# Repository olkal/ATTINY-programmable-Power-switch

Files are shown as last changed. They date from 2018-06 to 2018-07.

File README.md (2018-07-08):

# ATTINY Power switch
This programmable MOSFET high side on/off power switch is based on the ATTINY85 chip and is intended for battery powered devices.

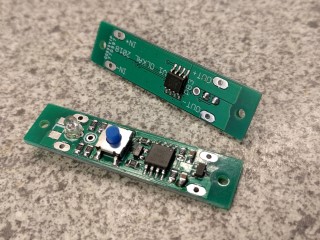
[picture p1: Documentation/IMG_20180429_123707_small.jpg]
ATTINY-Power-switch


- 2-3 Lipo cells 
- Max operating voltage 16.0V (18V never exceed)
- Max current: needs to be tested, but up to 5A should be safe. See MOSFET data sheet for info.
- Power consumption in "off" mode with BOD disabled: 3uA
- Power consumption in "off" mode with BOD enabled: 20uA

### Configurable features in config.h file:
- LED behaviour
- Low battery voltage threshold, LED warning
- Very low battery voltage threshold, power off
- Button press and hold for a set time for power on
- Button press and hold for set time for power off
- Timer, delayed power off
- Timer, after power has been on for set time, switch power off
- PB3 pin signal (to for example a Raspberry Pi) initiating controlled shut-down, then switch the power off after a set time delay
-  +lots of other possibilities...

### Battery/voltage features using button switch:
- Auto calibrating internal voltmeter
- Auto set number of cells

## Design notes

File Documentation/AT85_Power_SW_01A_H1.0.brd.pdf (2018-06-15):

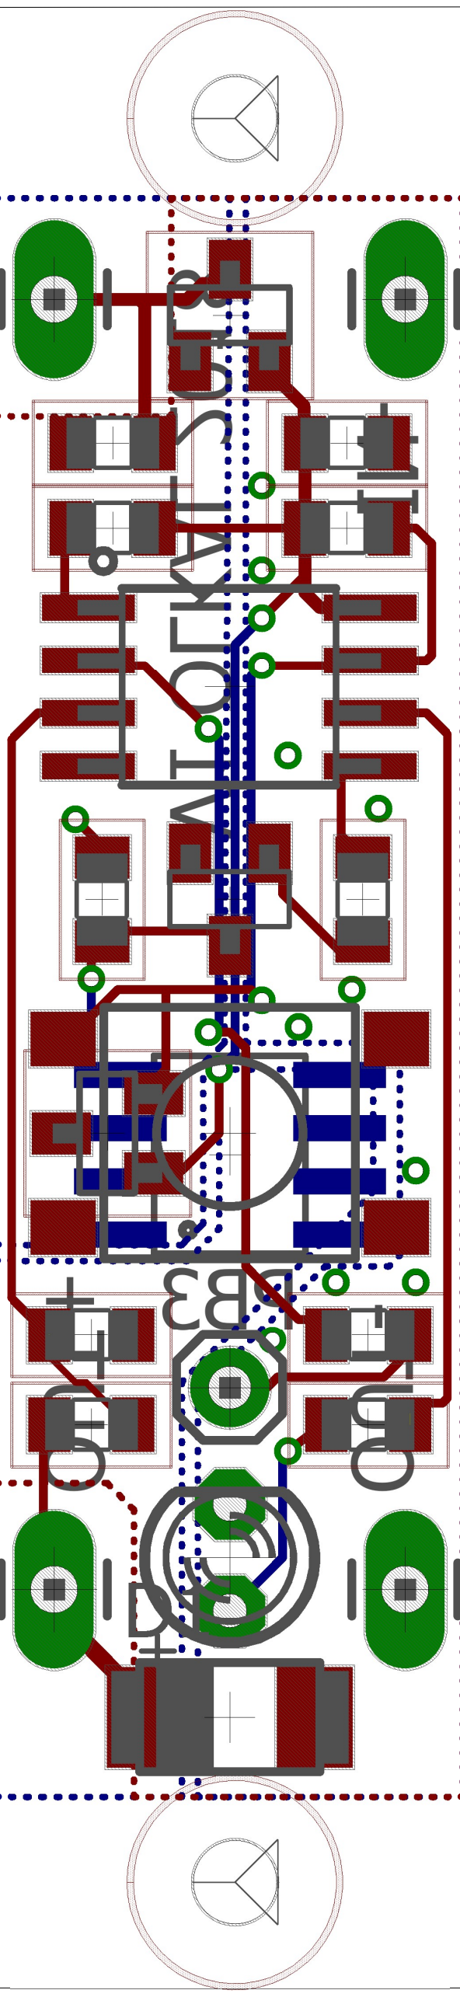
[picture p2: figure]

14.06.2018 20.10 f=4.00 D:\Dropbox\Hobby\Eagle\projects\Various\AT85_Power_SW\AT85_Power_SW_01A_H1.0.brd

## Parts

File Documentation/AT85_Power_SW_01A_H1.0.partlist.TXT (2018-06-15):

Partlist

Exported from AT85_Power_SW_01A_H1.0.sch at 14.06.2018 19.48

EAGLE Version 8.2.1 Copyright (c) 1988-2017 Autodesk, Inc.

Assembly variant: 

Part     Value             Device                               Package                       Library             Sheet

C2       4.7uF/25V         CAP_SMD_C0805                        C0805                         OKA-Cap-Resistor    1 
C3       4.7uF/25V         CAP_SMD_C0805                        C0805                         OKA-Cap-Resistor    1
D1                         DIODE-DO-214AC                       DO-214AC                      diode               1 -> Otional diode for inductive loads
IC1      3.3V              MCP1703A 3.3V regulator              SOT23                         linear              1
IC2      SL353             SL353                                SOT23                         OKA-IC              1 -> Otional hall sensor
LED1                       LED3MM                               LED3MM                        adafruit            1
Q1       P-MOSFET SI4459AD MOSFET-PCHANNEL                      SO08                          User-Submitted      1
R1       10k               RESISTOR_SMDR0805                    R0805                         OKA-Cap-Resistor    1
R2       100k              RESISTOR_SMDR0805                    R0805                         OKA-Cap-Resistor    1
R3       22k               RESISTOR_SMDR0805                    R0805                         OKA-Cap-Resistor    1
R4       1k5               RESISTOR_SMDR0805                    R0805                         OKA-Cap-Resistor    1
R5       220R              RESISTOR_SMDR0805                    R0805                         OKA-Cap-Resistor    1
R6       220R              RESISTOR_SMDR0805                    R0805                         OKA-Cap-Resistor    1
R7       10k               RESISTOR_SMDR0805                    R0805                         OKA-Cap-Resistor    1
R8       10k               RESISTOR_SMDR0805                    R0805                         OKA-Cap-Resistor    1
S1                         MOMENTARY-SWITCH-SPST-SMD-6.2MM-TALL TACTILE_SWITCH_SMD_6.2MM_TALL SparkFun-Switches   1
T1       2N2222            MMBT2222ALT1-NPN-SOT23-BEC           SOT23-BEC                     transistor          1
U1       Tiny85-20-SMT     ATTINY45TINY85-20-SMT                SO08-EIAJ_MCU                 SparkFun-Retired    1

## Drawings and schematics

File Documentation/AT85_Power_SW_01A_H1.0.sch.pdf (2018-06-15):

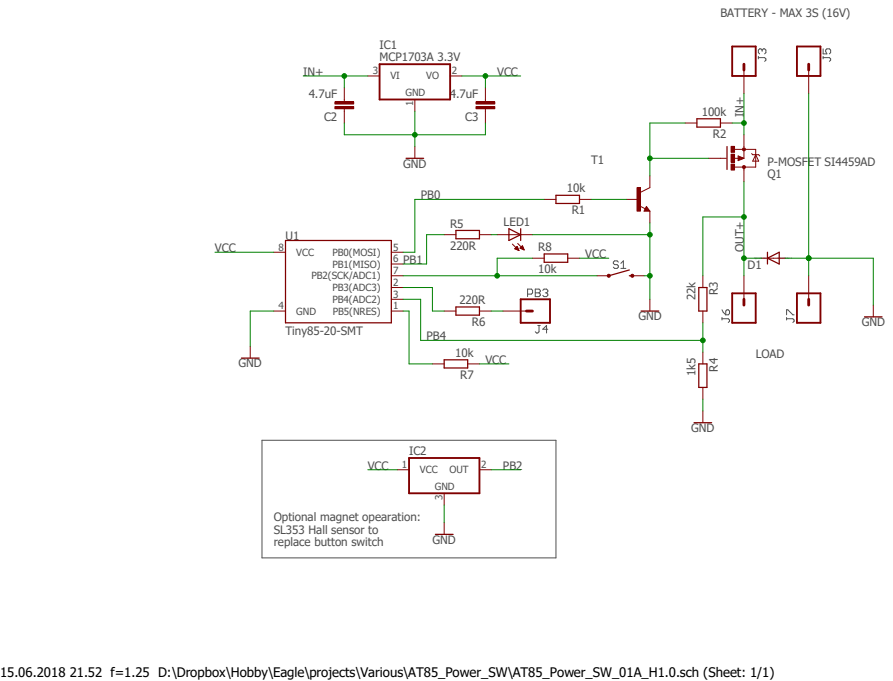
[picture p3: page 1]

15.06.2018 21.52 f=1.25 D:\Dropbox\Hobby\Eagle\projects\Various\AT85_Power_SW\AT85_Power_SW_01A_H1.0.sch (Sheet: 1/1)

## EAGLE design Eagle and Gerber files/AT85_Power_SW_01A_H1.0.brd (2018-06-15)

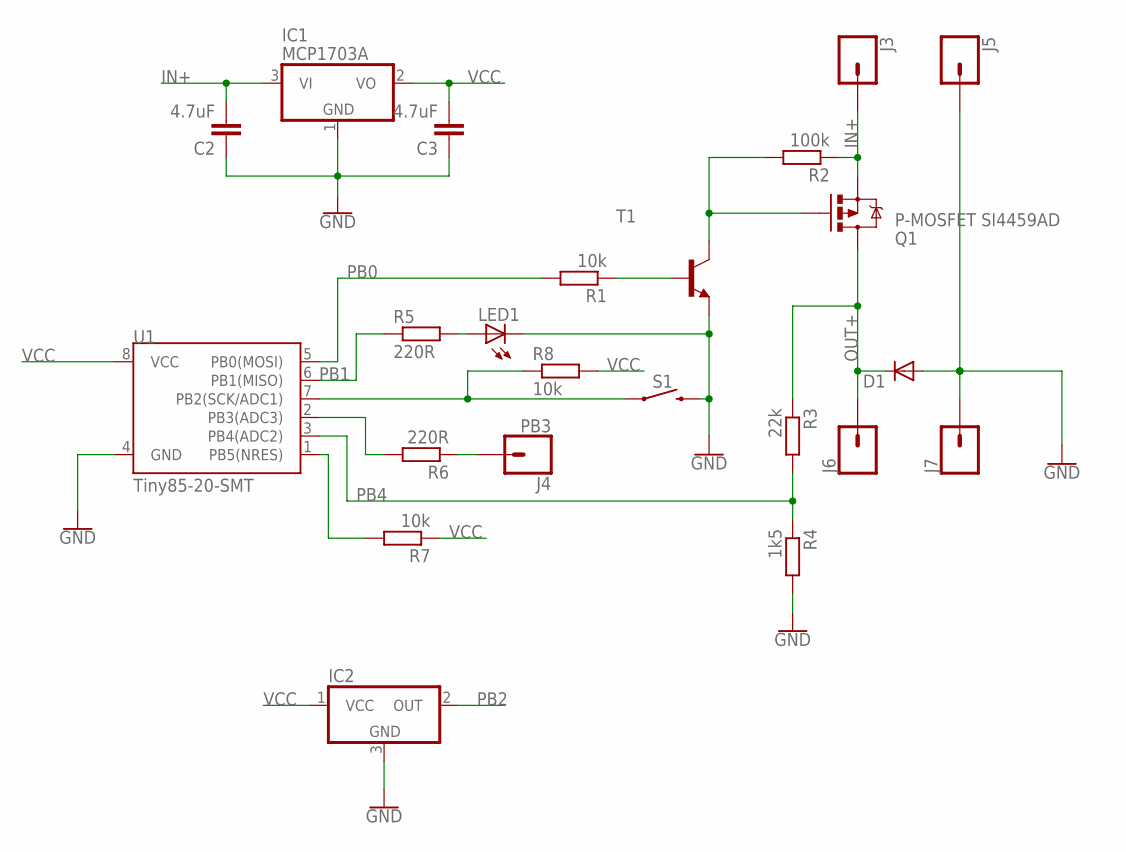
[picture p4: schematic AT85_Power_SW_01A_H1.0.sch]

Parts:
C2, C3: 4.7uF; C0805
D1: DIODE-DO-214AC; DO-214AC
IC1: MCP1703A; SOT23
IC2: SL353; SOT23
J3, J5, J6, J7: CONN_01PTH_LONGPAD; 1X01_LONGPAD
J4: PB3; 1X01
LED1: LED3MM
Q1: P-MOSFET SI4459AD; SO08
R1, R7, R8: 10k; R0805
R2: 100k; R0805
R3: 22k; R0805
R4: 1k5; R0805
R5, R6: 220R; R0805
S1: TACTILE_SWITCH_SMD_6.2MM_TALL
T1: MMBT2222ALT1-NPN-SOT23-BEC; SOT23-BEC
U1: Tiny85-20-SMT; SO08-EIAJ_MCU

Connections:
GATE: Q1.4 (G), R2.2, T1.C
GND: C2.1, C3.1, D1.A, IC1.1 (GND), IC2.3 (GND), J5.1, J7.1, LED1.K (C), R4.2, S1.B2 (2), T1.E, U1.4 (GND)
IN+: C2.2, IC1.3 (VI), J3.1, Q1.1 (S), Q1.2 (S), Q1.3 (S), R2.1
unnamed: LED1.A, R5.2
unnamed: R1.1, T1.B
OUT+: D1.C, J6.1, Q1.5 (D), Q1.6 (D), Q1.7 (D), Q1.8 (D), R3.1
PB0: R1.2, U1.5 (PB0(MOSI))
PB1: R5.1, U1.6 (PB1(MISO))
PB2: IC2.2 (OUT), R8.1, S1.A2 (1), U1.7 (PB2(SCK/ADC1))
PB3: R6.2, U1.2 (PB3(ADC3))
PB3_: J4.1, R6.1
PB4: R3.2, R4.1, U1.3 (PB4(ADC2))
RST: R7.2, U1.1 (PB5(NRES))
VCC: C3.2, IC1.2 (VO), IC2.1 (VCC), R7.1, R8.2, U1.8 (VCC)

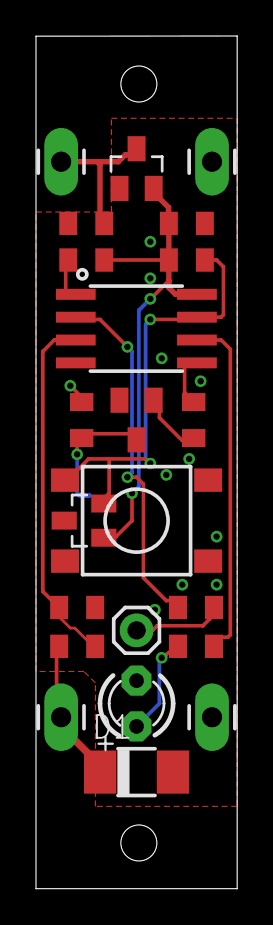
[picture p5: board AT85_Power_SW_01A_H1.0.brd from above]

Board: 2 copper layers, 11.2 x 47.4 mm, 23 parts (1 on the bottom side), 14 nets.

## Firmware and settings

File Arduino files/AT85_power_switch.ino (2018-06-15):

#include <Arduino.h>
#include <avr/interrupt.h>
#include <avr/sleep.h>
#include <EEPROM.h>
#include "config.h"

#define DEBOUNCE_MS                 30
#define POWER_OFF                   0x00
#define POWER_ON                    0x01
#define POWER_OFF_DELAY_WAIT        0x02
#define POWER_OFF_REQUEST           0x03
#define BATTERY_EMPTY               0x00
#define BATTERY_VERY_LOW            0x01
#define BATTERY_LOW                 0x02
#define BATTERY_GOOD                0x03
#define CELL_COUNT_MIN              0x01
#define CELL_COUNT_MAX              0x03

byte mosfetPin = 0;
byte ledPin = 1;
byte buttonPin = 2;
byte auxPin = 3;
byte battSensePin = A2;

int lastBattVal;
boolean lastButtonState = 1;
boolean buttonHold;
unsigned long buttonHoldTime;
unsigned long lastButtonAction;
unsigned long lastReadBattVoltage;
byte ledValue;
long ledTime;
long powerOnTime;
byte powerState = 0; //0=off, 1=on, 2=delayed shut down
byte battStatus = BATTERY_GOOD;
unsigned int voltageCalFactor;
byte cellCount;

void setup() {
  pinMode(ledPin, OUTPUT);
  pinMode(mosfetPin, OUTPUT);
  analogReference(INTERNAL);
  voltageCalFactor = word(EEPROM.read(0), EEPROM.read(1));
  cellCount = EEPROM.read(2);
  setPower(POWER_ON);
  delay(10);
  setConfig();
  for (byte c = 0; c < cellCount; c++) {
    digitalWrite(ledPin, 1);
    delay(200);
    digitalWrite(ledPin, 0);
    delay(200);
  }
  delay(200);
}

void loop() {
  checkSleep();
  checkTimerPwrOff();
  ledControl();
  if (powerState == POWER_OFF_DELAY_WAIT) {
    if ((lastButtonAction + AUX_SHTD_DELAY) < millis()) {
      setPower(POWER_OFF);
    }
  }
  else {
    button();
  }

  if ((lastReadBattVoltage + 250) < millis()) {
    readBattVoltage();
    lastReadBattVoltage = millis();
  }
  handleBattVoltage();
}

//**********************************

void ISR_wake()
{
}

void checkSleep() {
  if ((powerState == POWER_OFF) && (digitalRead(buttonPin) == HIGH)) {
    if ((lastButtonAction + 2000) < millis()) {
      if (SLEEP_ENABLE) {
        CPU_sleep();
      }
    }
  }
}

void checkTimerPwrOff() {
  if (TIMER_PWR_OFF_DELAY) {
    if (millis() > (powerOnTime + TIMER_PWR_OFF_DELAY)) {
      setPower(POWER_OFF_REQUEST);
    }
  }
}

void CPU_sleep()
{
  pinMode(auxPin, OUTPUT);
  pinMode(battSensePin, OUTPUT);
  digitalWrite(battSensePin, LOW);
  digitalWrite(auxPin, LOW);
  digitalWrite(ledPin, LOW);
  ADCSRA &= ~(1 << ADEN); //Disable ADC
  //byte gtccr = GTCCR;
  //GTCCR = 0;
  set_sleep_mode(SLEEP_MODE_PWR_DOWN);
  sleep_enable();
  attachInterrupt(0, ISR_wake, LOW);
  sleep_cpu(); //go to sleep
  detachInterrupt(0); //wake up
  sleep_disable(); 
  pinMode(battSensePin, INPUT);
  ADCSRA |= (1 << ADEN); //Enable ADC
  //GTCCR = gtccr;
  lastReadBattVoltage -= 250;
  lastButtonState = HIGH;
  pinMode(auxPin, INPUT);
}

void button() {
  boolean _buttonState = digitalRead(buttonPin);
  if (_buttonState != lastButtonState) {
    if (_buttonState == LOW) {
      if ((lastButtonAction + DEBOUNCE_MS) < millis()) {
        buttonHold = true;
      }
    }
    else {
      buttonHold = false;
    }
    lastButtonAction = millis();
    lastButtonState = _buttonState;
  }

  if (buttonHold) {
    if (powerState == POWER_OFF) {
      if ((lastButtonAction + BUTTON_PWR_ON_HOLD_TIME) <= millis()) {
        setPower(POWER_ON);
        buttonHold = false;
      }
    }
    else if (powerState == POWER_ON) {
      if ((lastButtonAction + BUTTON_PWR_OFF_HOLD_TIME) <= millis()) {
        setPower(POWER_OFF_REQUEST);
        buttonHold = false;
      }
    }
  }
}

void setPower(byte newlevel) {
  if (newlevel == POWER_OFF) {
    digitalWrite(mosfetPin, LOW);
    powerState = POWER_OFF;
  }
  else if (newlevel == POWER_ON) {
    digitalWrite(mosfetPin, HIGH);
    powerState = POWER_ON;
    powerOnTime = millis();
  }

  else if (newlevel == POWER_OFF_REQUEST) {
    if (powerState == POWER_ON) {
      if (AUX_IS_SHTD_SIGNAL_OUT) {
        powerState = POWER_OFF_DELAY_WAIT; //wait until power-off delay has counted down (RPI shut-down) 
        lastButtonAction = millis();
        auxControl();
      }
      else {
        digitalWrite(mosfetPin, LOW);
        powerState = POWER_OFF;
      }
    }
  }
}

void auxControl() {
  pinMode(auxPin, OUTPUT);
  boolean _val = AUX_SHTD_SIGNAL_HIGH_LOW;
  digitalWrite(auxPin, _val);
  delay(AUX_SHTD_SIGNAL_LENGTH);
  _val = ~_val; //flip
  digitalWrite(auxPin, _val);
  pinMode(auxPin, INPUT);
}

void ledControl() {
  int _ledontime;
  int _ledofftime;
  boolean _ledBlink;
  if (powerState == POWER_OFF) {
    ledValue = LED_OFF_BRIGHTNESS;
  }
  else if (powerState == POWER_ON) {
    if (battStatus == BATTERY_GOOD) {
      _ledBlink = 0;
      ledValue = LED_ON_BRIGHTNESS;
    }
    else if (battStatus == BATTERY_LOW) {
      _ledBlink = 1;
      _ledontime = LED_BLINK_ON_TIME * 2;
      _ledofftime = LED_BLINK_OFF_TIME;
    }
    else if (battStatus == BATTERY_EMPTY) {
      _ledBlink = 1;
      _ledontime = LED_BLINK_ON_TIME;
      _ledofftime = LED_BLINK_OFF_TIME;
    }
  }
  else if (powerState == POWER_OFF_DELAY_WAIT) {
    _ledBlink = 1;
    _ledontime = LED_BLINK_FAST_ON_TIME;
    _ledofftime = LED_BLINK_FAST_OFF_TIME;
  }
  if (_ledBlink) {
    if (ledTime < millis()) {
      if (ledValue < LED_ON_BRIGHTNESS) {
        ledValue = LED_ON_BRIGHTNESS;
        ledTime = millis() + _ledontime;
      }
      else {
        ledValue = LED_OFF_BRIGHTNESS;
        ledTime = millis() + _ledofftime;
      }
    }
  }
  analogWrite(ledPin, ledValue);
}

int readBattVoltage() {
  if (powerState) { //mosfet must be switched on for analog read battery voltage
    int _val;
    int _newval;
    _newval = analogRead(battSensePin);
    if (lastBattVal < _newval) { //use the highest of the two last conversions
      _val = _newval;
    }
    else {
      _val = lastBattVal;
    }

    _val = ((long)_val * (long)voltageCalFactor) / 100L;
    if (_val > (cellCount * CELL_VOLTAGE_LOW)) {
      battStatus = BATTERY_GOOD;
    }
    else if (_val > (cellCount * CELL_VOLTAGE_VERY_LOW)) {
      battStatus = BATTERY_LOW;
    }
    else if (_val > (cellCount * CELL_VOLTAGE_EMPTY)) {
      battStatus = BATTERY_VERY_LOW;
    }
    else {
      battStatus = BATTERY_EMPTY;
    }
    lastBattVal = _newval;
    return _val;
  }
}

void handleBattVoltage() {
  if ((battStatus == BATTERY_LOW) && BATTERY_LOW_AUTO_OFF) {
    if (millis() < (powerOnTime + 3000)) {
      setPower(POWER_OFF);
    }
    else {
      setPower(POWER_OFF_REQUEST);
    }
  }
  if ((battStatus == BATTERY_VERY_LOW) && BATTERY_VERY_LOW_AUTO_OFF) {
    if (millis() < (powerOnTime + 3000)) {
      setPower(POWER_OFF);
    }
    else {
      setPower(POWER_OFF_REQUEST);
    }
  }
  else if ((battStatus == BATTERY_EMPTY) && BATTERY_EMPTY_AUTO_OFF) {
    setPower(POWER_OFF);
  }
}

void setConfig() {
  if (digitalRead(buttonPin) == LOW) {
    boolean _buttonhold = 1;
    boolean _done = 0;
    digitalWrite(ledPin, 0);
    long _button_release_time = 0;
    while (1) {
      if ((millis() > 5000) && (millis() < 5050)) digitalWrite(ledPin, 1);
      else if ((millis() > 10000) && (millis() < 10050)) digitalWrite(ledPin, 1);
      else digitalWrite(ledPin, 0);

      if ((digitalRead(buttonPin) == HIGH) && (_button_release_time == 0)) {
        _button_release_time = millis();
      }

      else if (_button_release_time > 10000) {
        digitalWrite(ledPin, 1);
        calibrateBattVoltage();
        while (1) {
          digitalWrite(ledPin, 0);
          delay(1000);
          digitalWrite(ledPin, 1);
          delay(1000);
        }
      }
      else if (_button_release_time > 5000) {
        digitalWrite(ledPin, 1);
        int v = readBattVoltage();
        int _cellcount = v / CELL_VOLTAGE_LOW;
        if ((_cellcount > CELL_COUNT_MIN) && (_cellcount <= CELL_COUNT_MAX)) {
          EEPROM.write(2, (_cellcount & 0xFF));
          cellCount = EEPROM.read(2);
          while (1) {
            for (byte c = 0; c < cellCount; c++) {
              digitalWrite(ledPin, 1);
              delay(200);
              digitalWrite(ledPin, 0);
              delay(200);
            }
            delay(1000);
          }
        }
      }
    }
  }
}

int calibrateBattVoltage() {
  setPower(POWER_ON);
  delay(100);
  int _val = 0;
  for (byte i = 0; i < 10; i++) { //repeated readings
    _val += analogRead(battSensePin);
    delay(100);
  }
  _val = ((long)AUTO_CAL_VOLTAGE * 1000) / _val;

  EEPROM.write(0, (_val >> 8 & 0xFF)); //save new value, high byte
  EEPROM.write(1, (_val & 0xFF)); //save new value, low byte
}

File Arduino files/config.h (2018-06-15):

/*
   ATTINY fuse settings:
   1MHz (internal)
   BOD 2.7V (BOD 1.8V can be used for ATTINY85V) 
*/
/*
  Instructions to auto calibrate internal voltmeter:
    1. Disconnect load side of the switch
    2. Press and hold button
    3. Connect 5.00V power supply on battery side
    4. Release button after the second LED blink (10 seconds)
    5. LED will start to blink slowly when calibration is done
    6. Disconnect and reconnect adjustable power supply
    7. Test the calibration by adjusting the supply voltage while observing LED

  Instructions to configure the battery cell count:
    1. Disconnect load side of the switch
    2. Press and hold button
    3. Connect the battery
    4. Release button after the first LED blink (5 seconds)
    5. LED will start to blink the number of cells detected
    6. Disconnect and reconnect battery    
*/

//configue mcu sleep and low battery warning/power off levels:
#define SLEEP_ENABLE                1       //Enable mcu deep sleep when power off (off-state, low power consumption) 
#define BATTERY_LOW_AUTO_OFF        0       //Enable auto power off if voltage is less than CELL_VOLTAGE_LOW 
#define BATTERY_VERY_LOW_AUTO_OFF   1       //Enable auto power off if voltage is less than CELL_VOLTAGE_VERY_LOW
#define BATTERY_EMPTY_AUTO_OFF      1       //Enable imidiate power off if voltage is less than CELL_VOLTAGE_EMPTY
#define AUTO_CAL_VOLTAGE            500     //supplied voltage to VIN when performing auto calibration, unit 1/100 volt
#define CELL_VOLTAGE_EMPTY          250     //bat level - imidiate shut off if voltage is below, unit 1/100 volt
#define CELL_VOLTAGE_VERY_LOW       300     //bat level - controlled shut off if voltage is below, unit 1/100 volt
#define CELL_VOLTAGE_LOW            360     //bat level - warning if voltage is below, unit 1/100 volt

//configure button behaviour:
#define BUTTON_PWR_ON_HOLD_TIME     0       //press and hold button to turn power on (ms) 0=disable
#define BUTTON_PWR_OFF_HOLD_TIME    0       //press and hold button to turn power off (ms) 0=disable

//configure LED
#define LED_OFF_BRIGHTNESS          0       //max 255
#define LED_ON_BRIGHTNESS           127     //max 255
#define LED_BLINK_ON_TIME           500     //low battery blink on time (ms)
#define LED_BLINK_OFF_TIME          500     //low battery blink off time (ms)
#define LED_BLINK_FAST_ON_TIME      40
#define LED_BLINK_FAST_OFF_TIME     60

//configure safe shut down of Raspberry Pi before power off:
#define AUX_IS_SHTD_SIGNAL_OUT      1       //enable aux pin as signal for safe shut down of Raspberry Pi or similar  
#define AUX_SHTD_SIGNAL_HIGH_LOW    0       //0=shtd signal pull low, 1=shtd signal pull high (1 can be combined with a LED)
#define AUX_SHTD_SIGNAL_LENGTH      500     //signal to Raspberry duration (ms)
#define AUX_SHTD_DELAY              14000    //delay, from Raspberry Pi shut down is initiated until power off (ms)

//configure timer - power off after xx time has elapsed
#define TIMER_PWR_OFF_DELAY         0   //timer delay from power on until power off (ms), 0=disable

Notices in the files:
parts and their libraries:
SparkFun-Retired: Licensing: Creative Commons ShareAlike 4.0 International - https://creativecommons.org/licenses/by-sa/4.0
